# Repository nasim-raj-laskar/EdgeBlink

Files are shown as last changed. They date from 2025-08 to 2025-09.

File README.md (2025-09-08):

# EdgeBlink

**EdgeBlink** is a real-time object detection system running entirely on the ESP32-CAM using a quantized TensorFlow Lite model. Optimized with the EON™ Compiler, it delivers \~1.4 FPS with minimal memory usage, displays results on an OLED, and supports both USB and standalone battery-powered operation for portable AI-IoT applications.

<div align="center" style="border: 2 px solid #ccc; padding: 10 px; display: inline-block;">
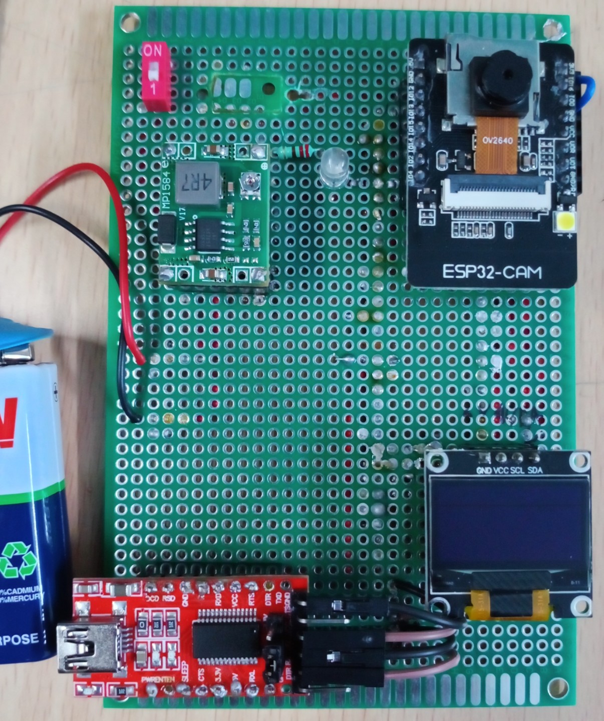
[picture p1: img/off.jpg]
  
</div>
<div align="center" style="border: 2 px solid #ccc; padding: 10 px; display: inline-block;">
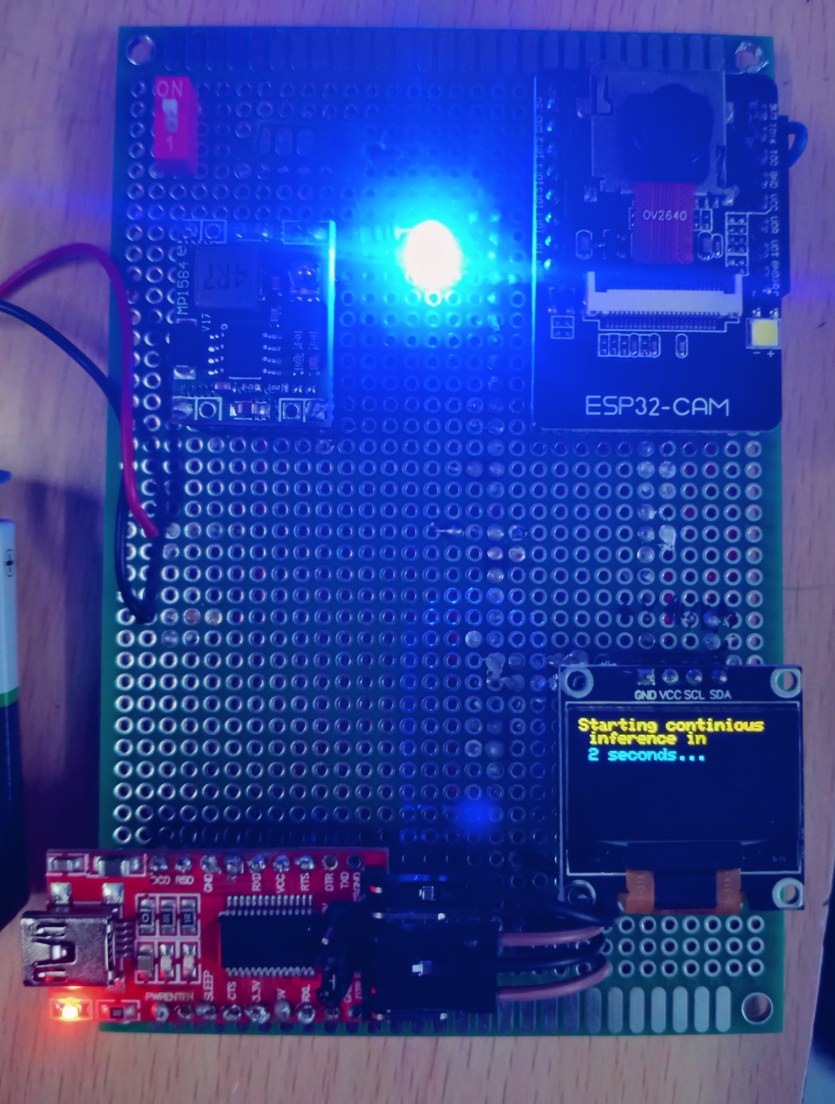
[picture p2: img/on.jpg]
  
  <P><i>sorry abt the intensity of the power led...and poor photography</i></P>
</div>

## 🚀 Features

- **Real-time Object Detection**: Detects bitter gourd, onions, and tomatoes
- **High Accuracy**: 100% F1 score on validation set
- **Optimized Performance**: 695ms inference time with quantized int8 model
- **Low Memory Footprint**: 239.4K RAM usage, 81.1K flash usage
- **OLED Display**: Real-time detection results visualization
- **Independent Power Supply**: MP1584 buck converter support for standalone operation

## 📊 Model Performance

### Training Results
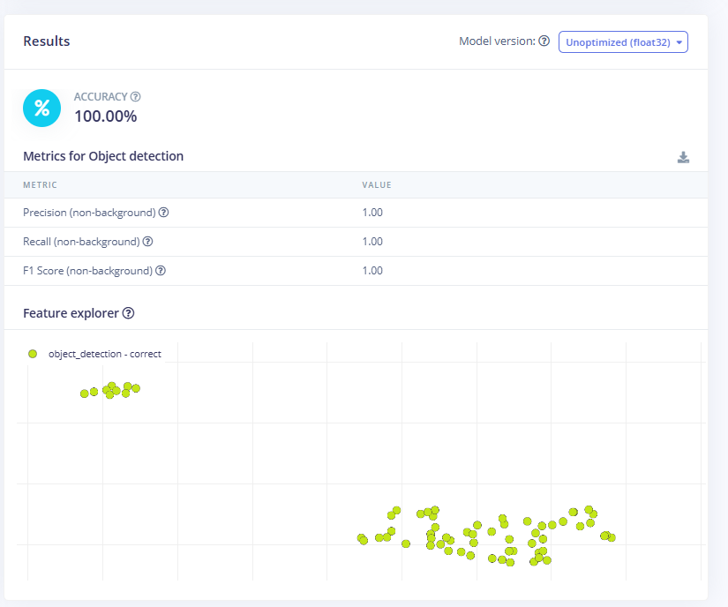
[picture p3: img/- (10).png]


- **F1 Score**: 100.0%
- **Precision**: 1.00
- **Recall**: 1.00
- **Model Version**: Quantized (int8)

### Confusion Matrix
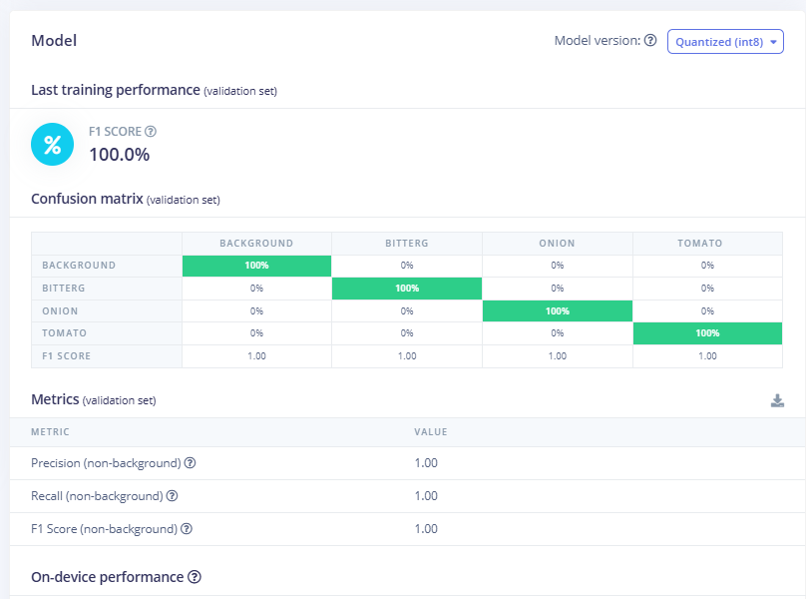
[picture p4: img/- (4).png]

The model achieves perfect classification across all three classes:

| Class | Background | Bitter Gourd | Onion | Tomato |
|---|---|---|---|---|
| **Background** | 100% | 0% | 0% | 0% |
| **Bitter Gourd** | 0% | 100% | 0% | 0% |
| **Onion** | 0% | 0% | 100% | 0% |
| **Tomato** | 0% | 0% | 0% | 100% |

### Training Data Distribution
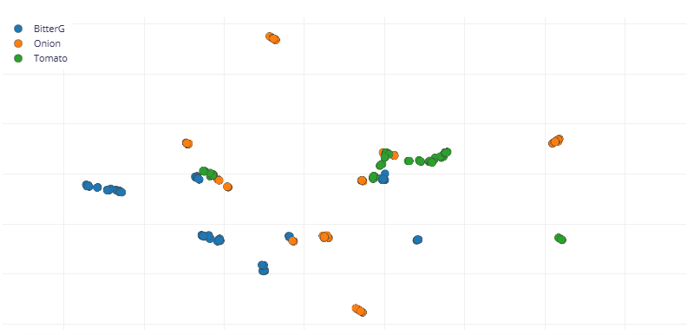
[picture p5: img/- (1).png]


The model was trained on a balanced dataset with samples distributed across different scenarios and lighting conditions.

## ⚡ Performance Metrics

### On-Device Performance
ESP32-CAM Setup

- **Inference Time**: 695ms
- **Peak RAM Usage**: 119.4K
- **Flash Usage**: 81.1K
- **Overall Accuracy**: 98.46%

### Detailed Timing Breakdown
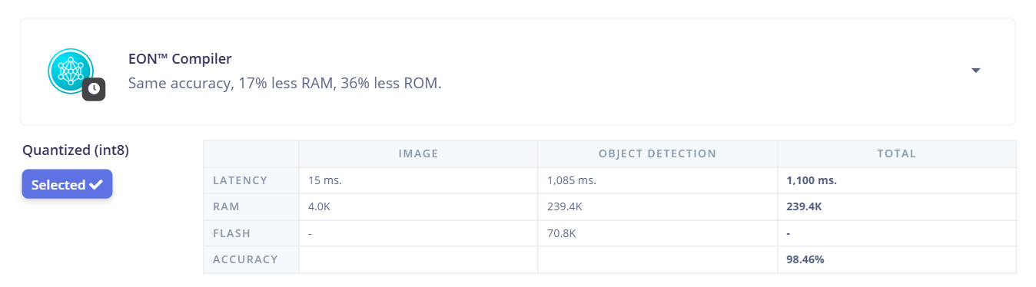
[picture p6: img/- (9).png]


- **Image Processing**: 15ms latency, 4.0K RAM
- **Object Detection**: 1,085ms latency, 239.4K RAM
- **Total Pipeline**: 1,100ms

## 🔧 Hardware Requirements

| **Component** | **Details** |
|---|---|
| **ESP32-CAM Module** | OV2640 camera sensor |
| **OLED Display** | 128x64 resolution |
| **MP1584 Buck Converter** | Adjustable output for independent power supply |
| **FTDI USB-to-Serial Converter** | For development and programming |
| **Prototyping PCB** | For assembling components |
| **Header Pins & Jumper Wires** | For connections |

| **Power Supply Mode** | **Description** | **Specifications** |
|---|---|---|
| **Development Mode** | USB power via FTDI module | Flashing code via USB hub |
| **Production Mode** | MP1584 buck converter for standalone battery operation | Input: 4.5V–28V, Output: 5V adjustable, Up to 3A |

## 📁 Project Structure

```
EdgeBlink/
├── img/                               # Documentation images
├── pcb/                               # PCB design files
│   ├── dct.kicad_prl                  # KiCad project files
│   ├── dct.kicad_pro                  # KiCad pro files
│   ├── dct.kicad_sch                  # Schematic files
│   └── fp-info-cache                  # Footprint cache
├── src/                               # Source code
│   ├── edge-impulse-sdk/              # Edge Impulse SDK
│   ├── model-parameters/              # Model configuration
│   ├── tflite-model/                  # TensorFlow Lite model
│   └── detect-esp32cam_inferencing.h  # Main inference header
│ 
├── detect.ino                         # Main Arduino sketch
├── library.properties                 # Library properties
└── README.md                          # This file
```

## 💻 Real-Time Detection Output

The system provides real-time detection feedback through serial output:

ESP32-CAM Setup
ESP32-CAM Setup

## 🔧 Model Optimization

The model uses several optimization techniques for ESP32 deployment:

### EON™ Compiler Optimization
- **17% less RAM usage**
- **36% less ROM usage** 
- **Same accuracy maintained**

### Quantization Benefits
- **Model Type**: Quantized (int8)
- **Size Reduction**: Significant memory footprint reduction
- **Speed Improvement**: Faster inference times
- **Accuracy Retention**: No loss in detection accuracy

ESP32-CAM Setup

## 📈 Technical Specifications

### Performance Characteristics
- **Frame Rate**: ~1.4 FPS (695ms inference + processing time)
- **Resolution**: Optimized for ESP32-CAM sensor capabilities
- **Detection Range**: Optimized for close-range object identification
- **Power Consumption**: Low power design suitable for battery operation

## 🙏 Acknowledgments

- Edge Impulse for the machine learning platform
- ESP32 community for hardware support
- TensorFlow Lite team for model optimization tools

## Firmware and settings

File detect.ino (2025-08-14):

/*
*ESP32 cam object detection code
* by circuirdigest on 27-June-2024
*/
#include <detect-esp32cam_inferencing.h>
#include "edge-impulse-sdk/dsp/image/image.hpp"

#include "esp_camera.h"
// Select camera model - find more camera models in camera_pins.h file here
// https://github.com/espressif/arduino-esp32/blob/master/libraries/ESP32/…
// #define CAMERA_MODEL_ESP_EYE  // Has PSRAM
#define CAMERA_MODEL_AI_THINKER // Has PSRAM
#if defined(CAMERA_MODEL_ESP_EYE)
#define PWDN_GPIO_NUM -1
#define RESET_GPIO_NUM -1
#define XCLK_GPIO_NUM 4
#define SIOD_GPIO_NUM 18
#define SIOC_GPIO_NUM 23
#define Y9_GPIO_NUM 36
#define Y8_GPIO_NUM 37
#define Y7_GPIO_NUM 38
#define Y6_GPIO_NUM 39
#define Y5_GPIO_NUM 35
#define Y4_GPIO_NUM 14
#define Y3_GPIO_NUM 13
#define Y2_GPIO_NUM 34
#define VSYNC_GPIO_NUM 5
#define HREF_GPIO_NUM 27
#define PCLK_GPIO_NUM 25
#elif defined(CAMERA_MODEL_AI_THINKER)
#define PWDN_GPIO_NUM 32
#define RESET_GPIO_NUM -1
#define XCLK_GPIO_NUM 0
#define SIOD_GPIO_NUM 26
#define SIOC_GPIO_NUM 27
#define Y9_GPIO_NUM 35
#define Y8_GPIO_NUM 34
#define Y7_GPIO_NUM 39
#define Y6_GPIO_NUM 36
#define Y5_GPIO_NUM 21
#define Y4_GPIO_NUM 19
#define Y3_GPIO_NUM 18
#define Y2_GPIO_NUM 5
#define VSYNC_GPIO_NUM 25
#define HREF_GPIO_NUM 23
#define PCLK_GPIO_NUM 22
#else
#error "Camera model not selected"
#endif
/* Constant defines -------------------------------------------------------- */
#define EI_CAMERA_RAW_FRAME_BUFFER_COLS 320
#define EI_CAMERA_RAW_FRAME_BUFFER_ROWS 240
#define EI_CAMERA_FRAME_BYTE_SIZE 3
#include <Wire.h>
#include <Adafruit_GFX.h>
#include <Adafruit_SSD1306.h>

#define I2C_SDA 15
#define I2C_SCL 14
TwoWire I2Cbus = TwoWire(0);
// Display defines
#define SCREEN_WIDTH 128
#define SCREEN_HEIGHT 64
#define OLED_RESET -1
#define SCREEN_ADDRESS 0x3C
Adafruit_SSD1306 display(SCREEN_WIDTH, SCREEN_HEIGHT, &I2Cbus, OLED_RESET);
/* Private variables ------------------------------------------------------- */
static bool debug_nn = false;  
static bool is_initialised = false;
uint8_t *snapshot_buf;  //points to the output of the capture
static camera_config_t camera_config = {
  .pin_pwdn = PWDN_GPIO_NUM,
  .pin_reset = RESET_GPIO_NUM,
  .pin_xclk = XCLK_GPIO_NUM,
  .pin_sscb_sda = SIOD_GPIO_NUM,
  .pin_sscb_scl = SIOC_GPIO_NUM,
  .pin_d7 = Y9_GPIO_NUM,
  .pin_d6 = Y8_GPIO_NUM,
  .pin_d5 = Y7_GPIO_NUM,
  .pin_d4 = Y6_GPIO_NUM,
  .pin_d3 = Y5_GPIO_NUM,
  .pin_d2 = Y4_GPIO_NUM,
  .pin_d1 = Y3_GPIO_NUM,
  .pin_d0 = Y2_GPIO_NUM,
  .pin_vsync = VSYNC_GPIO_NUM,
  .pin_href = HREF_GPIO_NUM,
  .pin_pclk = PCLK_GPIO_NUM,
  //XCLK 20MHz or 10MHz for OV2640 double FPS (Experimental)
  .xclk_freq_hz = 20000000,
  .ledc_timer = LEDC_TIMER_0,
  .ledc_channel = LEDC_CHANNEL_0,
  .pixel_format = PIXFORMAT_JPEG,  //YUV422,GRAYSCALE,RGB565,JPEG
  .frame_size = FRAMESIZE_QVGA,    //QQVGA-UXGA Do not use sizes above QVGA when not JPEG
  .jpeg_quality = 12,  //0-63 lower number means higher quality
  .fb_count = 1,       //if more than one, i2s runs in continuous mode. Use only with JPEG
  .fb_location = CAMERA_FB_IN_PSRAM,
  .grab_mode = CAMERA_GRAB_WHEN_EMPTY,
};
/* Function definitions ------------------------------------------------------- */
bool ei_camera_init(void);
void ei_camera_deinit(void);
bool ei_camera_capture(uint32_t img_width, uint32_t img_height, uint8_t *out_buf);
/**
* @brief      Arduino setup function
*/
void setup() {
  // put your setup code here, to run once:
  Serial.begin(115200);
  // Initialize I2C with our defined pins
  I2Cbus.begin(I2C_SDA, I2C_SCL, 100000);
  // SSD1306_SWITCHCAPVCC = generate display voltage from 3.3V internally
  if (!display.begin(SSD1306_SWITCHCAPVCC, SCREEN_ADDRESS)) {
    Serial.printf("SSD1306 OLED display failed to initalize.\nCheck that display SDA is connected to pin %d and SCL connected to pin %d\n", I2C_SDA, I2C_SCL);
    while (true)
      ;
  }
  //comment out the below line to start inference immediately after upload
  while (!Serial)
    ;
  Serial.println("Edge Impulse Inferencing Demo");
  if (ei_camera_init() == false) {
    ei_printf("Failed to initialize Camera!\r\n");
  } else {
    ei_printf("Camera initialized\r\n");
  }
  ei_printf("\nStarting continious inference in 2 seconds...\n");
   display.clearDisplay();
  display.setCursor(0, 0);
  display.setTextSize(1);
  display.setTextColor(SSD1306_WHITE);
  display.print("Starting continious\n inference in\n 2 seconds...");
  display.display();
  ei_sleep(2000);
    display.clearDisplay();
}
/**
* @brief      Get data and run inferencing
*
* @param[in]  debug  Get debug info if true
*/
void loop() {
  display.clearDisplay();
  // instead of wait_ms, we'll wait on the signal, this allows threads to cancel us...
  if (ei_sleep(5) != EI_IMPULSE_OK) {
    return;
  }
  snapshot_buf = (uint8_t *)malloc(EI_CAMERA_RAW_FRAME_BUFFER_COLS * EI_CAMERA_RAW_FRAME_BUFFER_ROWS * EI_CAMERA_FRAME_BYTE_SIZE);
  // check if allocation was successful
  if (snapshot_buf == nullptr) {
    ei_printf("ERR: Failed to allocate snapshot buffer!\n");
    return;
  }
  ei::signal_t signal;
  signal.total_length = EI_CLASSIFIER_INPUT_WIDTH * EI_CLASSIFIER_INPUT_HEIGHT;
  signal.get_data = &ei_camera_get_data;
  if (ei_camera_capture((size_t)EI_CLASSIFIER_INPUT_WIDTH, (size_t)EI_CLASSIFIER_INPUT_HEIGHT, snapshot_buf) == false) {
    ei_printf("Failed to capture image\r\n");
    free(snapshot_buf);
    return;
  }
  // Run the classifier
  ei_impulse_result_t result = { 0 };
  EI_IMPULSE_ERROR err = run_classifier(&signal, &result, debug_nn);
  if (err != EI_IMPULSE_OK) {
    ei_printf("ERR: Failed to run classifier (%d)\n", err);
    return;
  }
  // print the predictions
  ei_printf("Predictions (DSP: %d ms., Classification: %d ms., Anomaly: %d ms.): \n",
            result.timing.dsp, result.timing.classification, result.timing.anomaly);
#if EI_CLASSIFIER_OBJECT_DETECTION == 1
  bool bb_found = result.bounding_boxes[0].value > 0;
  for (size_t ix = 0; ix < result.bounding_boxes_count; ix++) {
    auto bb = result.bounding_boxes[ix];
    if (bb.value == 0) {
      continue;
    }
    ei_printf("    %s (%f) [ x: %u, y: %u, width: %u, height: %u ]\n", bb.label, bb.value, bb.x, bb.y, bb.width, bb.height);
  display.setCursor(0, 20 * ix);
    display.setTextSize(2);
    display.setTextColor(SSD1306_WHITE);
    display.print(bb.label);
    display.print("-");
    display.print(int((bb.value)*100));
    display.print("%");
    display.display();
  }
  if (!bb_found) {
    ei_printf("    No objects found\n");
    display.setCursor(0, 16);
    display.setTextSize(2);
    display.setTextColor(SSD1306_WHITE);
    display.print("No objects  found");
    display.display();
  }
#else
  for (size_t ix = 0; ix < EI_CLASSIFIER_LABEL_COUNT; ix++) {
    ei_printf("    %s: %.5f\n", result.classification[ix].label,
              result.classification[ix].value);
  }
#endif
#if EI_CLASSIFIER_HAS_ANOMALY == 1
  ei_printf("    anomaly score: %.3f\n", result.anomaly);
#endif
  free(snapshot_buf);
}
/**
 * @brief   Setup image sensor & start streaming
 *
 * @retval  false if initialisation failed
 */
bool ei_camera_init(void) {
  if (is_initialised) return true;
#if defined(CAMERA_MODEL_ESP_EYE)
  pinMode(13, INPUT_PULLUP);
  pinMode(14, INPUT_PULLUP);
#endif
  //initialize the camera
  esp_err_t err = esp_camera_init(&camera_config);
  if (err != ESP_OK) {
    Serial.printf("Camera init failed with error 0x%x\n", err);
    return false;
  }
  sensor_t *s = esp_camera_sensor_get();
  // initial sensors are flipped vertically and colors are a bit saturated
  if (s->id.PID == OV3660_PID) {
    s->set_vflip(s, 1);       // flip it back
    s->set_brightness(s, 1);  // up the brightness just a bit
    s->set_saturation(s, 0);  // lower the saturation
  }
#if defined(CAMERA_MODEL_M5STACK_WIDE)
  s->set_vflip(s, 1);
  s->set_hmirror(s, 1);
#elif defined(CAMERA_MODEL_ESP_EYE)
  s->set_vflip(s, 1);
  s->set_hmirror(s, 1);
  s->set_awb_gain(s, 1);
#endif
  is_initialised = true;
  return true;
}
/**
 * @brief      Stop streaming of sensor data
 */
void ei_camera_deinit(void) {
  //deinitialize the camera
  esp_err_t err = esp_camera_deinit();
  if (err != ESP_OK) {
    ei_printf("Camera deinit failed\n");
    return;
  }
  is_initialised = false;
  return;
}
/**
 * @brief      Capture, rescale and crop image
 *
 * @param[in]  img_width     width of output image
 * @param[in]  img_height    height of output image
 * @param[in]  out_buf       pointer to store output image, NULL may be used
 *                           if ei_camera_frame_buffer is to be used for capture and resize/cropping.
 *
 * @retval     false if not initialised, image captured, rescaled or cropped failed
 *
 */
bool ei_camera_capture(uint32_t img_width, uint32_t img_height, uint8_t *out_buf) {
  bool do_resize = false;
  if (!is_initialised) {
    ei_printf("ERR: Camera is not initialized\r\n");
    return false;
  }
  camera_fb_t *fb = esp_camera_fb_get();
  if (!fb) {
    ei_printf("Camera capture failed\n");
    return false;
  }
  bool converted = fmt2rgb888(fb->buf, fb->len, PIXFORMAT_JPEG, snapshot_buf);
  esp_camera_fb_return(fb);
  if (!converted) {
    ei_printf("Conversion failed\n");
    return false;
  }
  if ((img_width != EI_CAMERA_RAW_FRAME_BUFFER_COLS)
      || (img_height != EI_CAMERA_RAW_FRAME_BUFFER_ROWS)) {
    do_resize = true;
  }
  if (do_resize) {
    ei::image::processing::crop_and_interpolate_rgb888(
      out_buf,
      EI_CAMERA_RAW_FRAME_BUFFER_COLS,
      EI_CAMERA_RAW_FRAME_BUFFER_ROWS,
      out_buf,
      img_width,
      img_height);
  }
  return true;
}
static int ei_camera_get_data(size_t offset, size_t length, float *out_ptr) {
  // we already have a RGB888 buffer, so recalculate offset into pixel index
  size_t pixel_ix = offset * 3;
  size_t pixels_left = length;
  size_t out_ptr_ix = 0;
  while (pixels_left != 0) {
    // Swap BGR to RGB here
    // due to https://github.com/espressif/esp32-camera/issues/379
    out_ptr[out_ptr_ix] = (snapshot_buf[pixel_ix + 2] << 16) + (snapshot_buf[pixel_ix + 1] << 8) + snapshot_buf[pixel_ix];
    // go to the next pixel
    out_ptr_ix++;
    pixel_ix += 3;
    pixels_left--;
  }
  // and done!
  return 0;
}
#if !defined(EI_CLASSIFIER_SENSOR) || EI_CLASSIFIER_SENSOR != EI_CLASSIFIER_SENSOR_CAMERA
#error "Invalid model for current sensor"
#endif
